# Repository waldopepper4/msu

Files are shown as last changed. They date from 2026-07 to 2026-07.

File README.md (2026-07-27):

[README.md](https://github.com/user-attachments/files/30384597/README.md)
Stoppuhr für die Arduino-IDE bzw. C++. 
Die Stoppuhr kann nur eine voreingestellte Minutenanzahl abwärts zählen. 
Eine Start- /Stopptaste startet bzw. stoppt den Zähler. Der Endwert bleibt so lange im Display stehen, bis die Resettaste gedrückt wird. 
Eine Resettaste setzt den Zähler wieder auf den Anfangswert. 
Ein langes Drücken der Resettaste erlaubt die Minuten einzustellen: mit der Start- / Stopptaste kann der Wert erhöht werden, ein langes Drücken verringert den Minutenwert. Ein nochmaliges Drücken der Resettaste speichert den Minuten-Startwert. 
Bei Überlauf wird eine Minus- bzw. Überzeit solange angezeigt, bis mit der Start- / Stopptaste der Zähler gestoppt wird. Beim Erreichen der letzten 30, 20 und 10 Sekunden ertönt ein Piepser, bei 9,8,7,6,5,4,3,2 und 1 Sekunde weitere kurze Piepstöne und bei 00:00 ein langer Piepston. 
Verwendet wurde microchip ATtiny 3216 mit Display DOGM081.
Wenn die Spannung von 3,1V der Lithium-Batteriezelle unterschritten wird, erscheint "BATTLOW". Der Strombedarf im Betrieb ist ca. 1,7mA, im sleep-Mode 15uA, daher ist kein Ein-/Ausschalter nötig. Die verwendete Batterie hat eine  Sicherheitsschaltung und zusätzlich hat die Ladeschaltung TP4056 eine Batterie-Überwachung.

totale

Angaben zum Gehäuse:
msu.f3d ist der CAD-file für fusion360.
msu.step für andere CAD-Programme verwendbar.
Die *.stl zum direkten Drucken, alle Teile in Drucklage gespeichert.
Gehäuseteile gedruckt mit PCblend, ASA oder ABS im Prusa coreone. 0,2mm Schichthöhe, falls mit Rand, dann Finish der Kanten mit Schleifschwamm nötig.
Start-/Stopp- und Reset-Knopf mit Prusa-MK3S PLA 0,2mm, das transparente Fensterchen mit PETG, 0,1mm Schichthöhe.
Teilelisteund Bezug siehe Tabellenblatt BOM-msu.

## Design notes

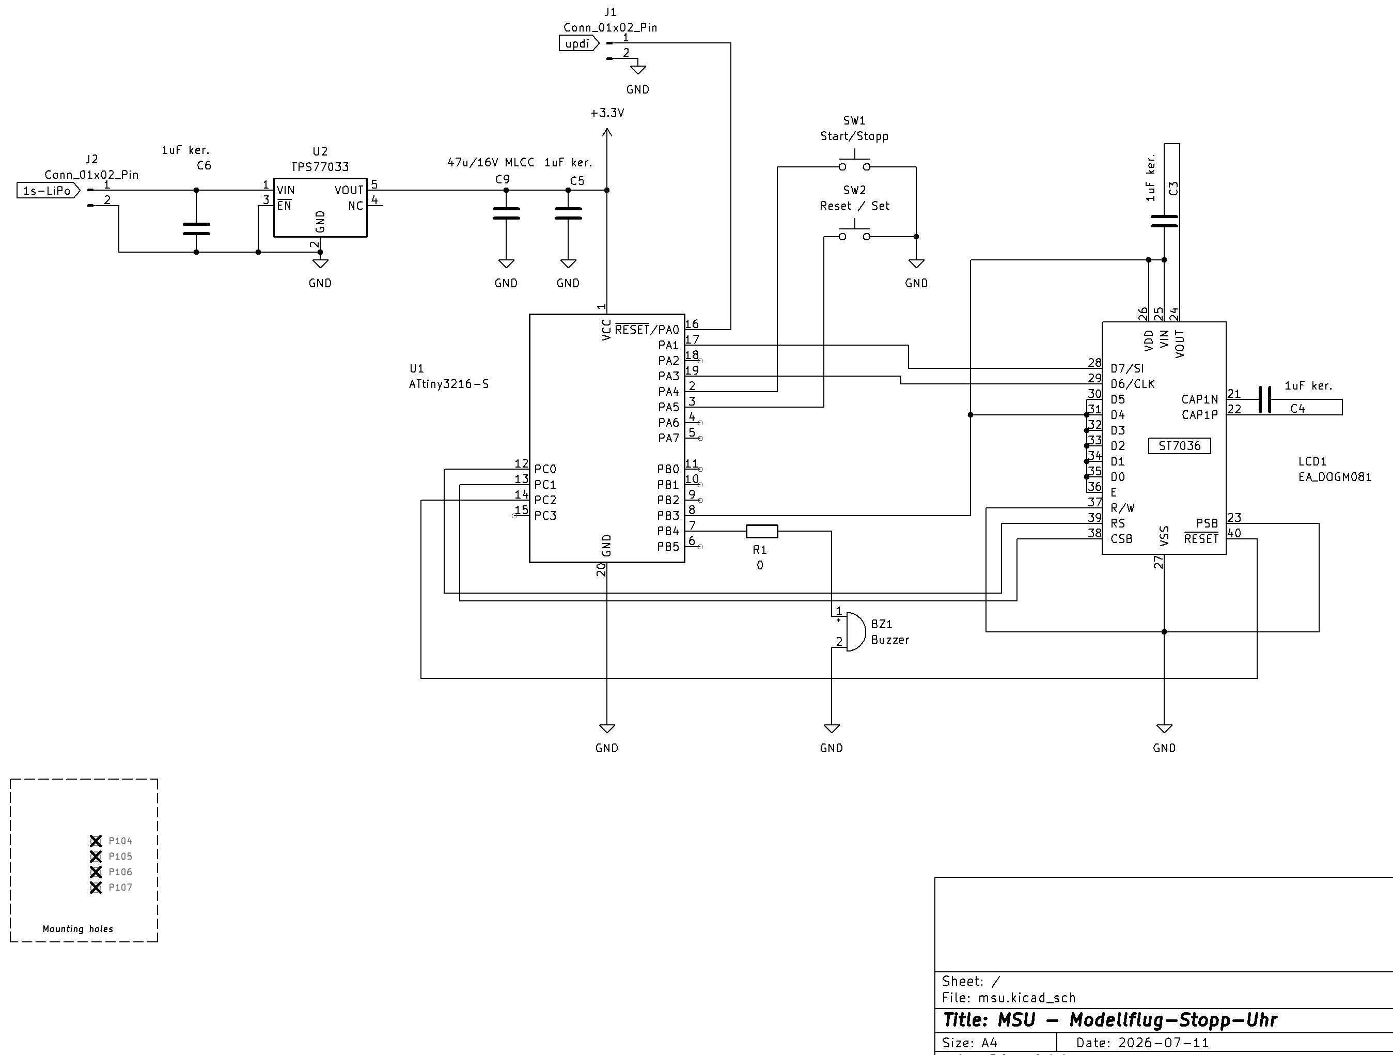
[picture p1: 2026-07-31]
hardware/msu 2026-07-11.jpg

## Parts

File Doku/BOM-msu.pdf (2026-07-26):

Tabelle1

Seite 1

Stk
Stk | Piezosummer, 75 dB, 3,0 V, 4000 Hz, SMD | SMD-P12A03 | reichelt.de | 1,41
Stk | LDO-Festspannungsregler, 2,7 - 10Vin, 3.3Vout, 50mAout, SOT-23-5 | TPS 77033 DBVT | reichelt.de | 1,41
Stk | 8-Bit-ATtiny AVR-RISC Mikrocontroller, 32 kB, 20 MHz, SOIC-20 | ATTINY3216-SN | reichelt.de | 1,76
Stk | SMD-Kerko, 1812, 10 µF, 25 V, 10%, MLCC | ECC KTS250B106K | reichelt.de | 0,57
Stk | 1uF MLCC
Stk | 47uF MLCC
Stk | 0R 0805
1 | IC-Fassung 40pol, lowcost
2 | APEM PHAP3305A PHAP3305A Drucktaster 12 V/DC 0.05 A 1 x Aus/(Ein) tastend | 700019 - 62 | conrad.at | 0,69
1 | Akyga LP523450 Akkupack x Spezial-Akku LiPo 3.7 V 900 mAh | 3385843 - 62 | conrad.at | 9,99
1 | TP4056 1A Lithium-Ionen LiPo Lademodul für Arduino USB-C | BAT7160 | techfun.sk | 0,45
1 | LCD-Textmodul, 29,8 x 10,4 mm, weiß | EA DOGS104N-A | reichelt.de | 6,50
1 | Arduino Nano-Klon mit USB-C | ARD958 | techfun.sk | 5,45
1 | Leerplatine nur 5Stk. Minimumbestellung | Y12-6321110A | jlcpcb.com | 6,00
4 | Senkkopfschraube M2x6
2 | Linsenkpfschraube M2x6
| | | Summe | 34,23 Euro

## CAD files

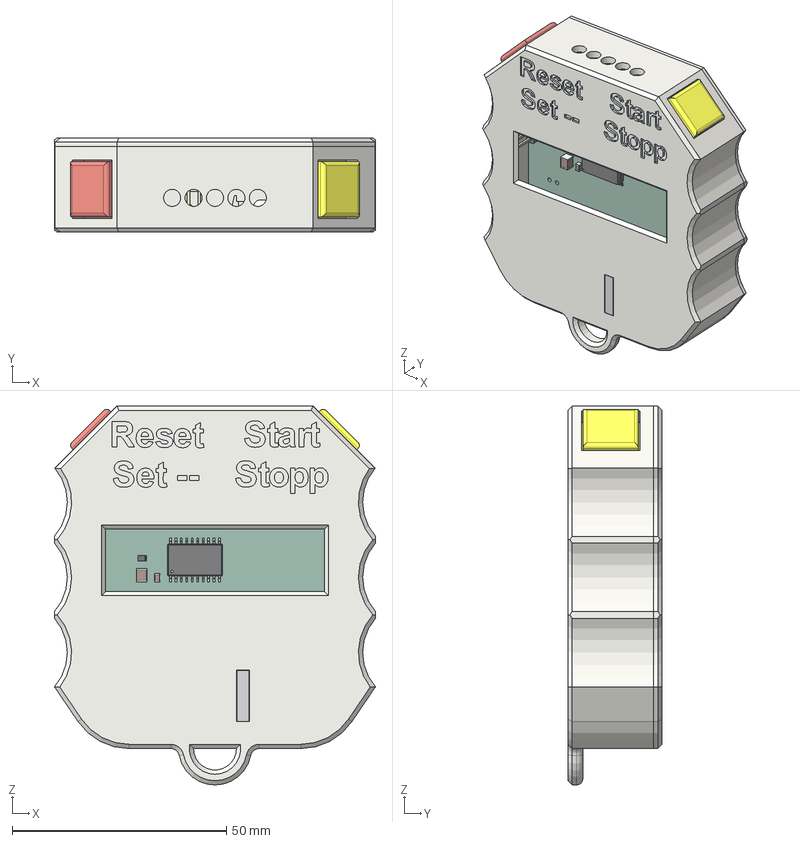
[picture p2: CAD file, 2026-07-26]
STL+CAD/msu.step
74.9 x 22.0 x 88.4 mm
SW_Tactile_SPST_Angled_PTS645Vx31-2LFS x 2
C_0805_2012Metric x 4
SOIC-20W_7.5x12.8mm_P1.27mm
SOT-23-5
PinHeader_1x02_P2.54mm_Vertical x 2
R_0805_2012Metric
C_1210_3225Metric
msu_PCB

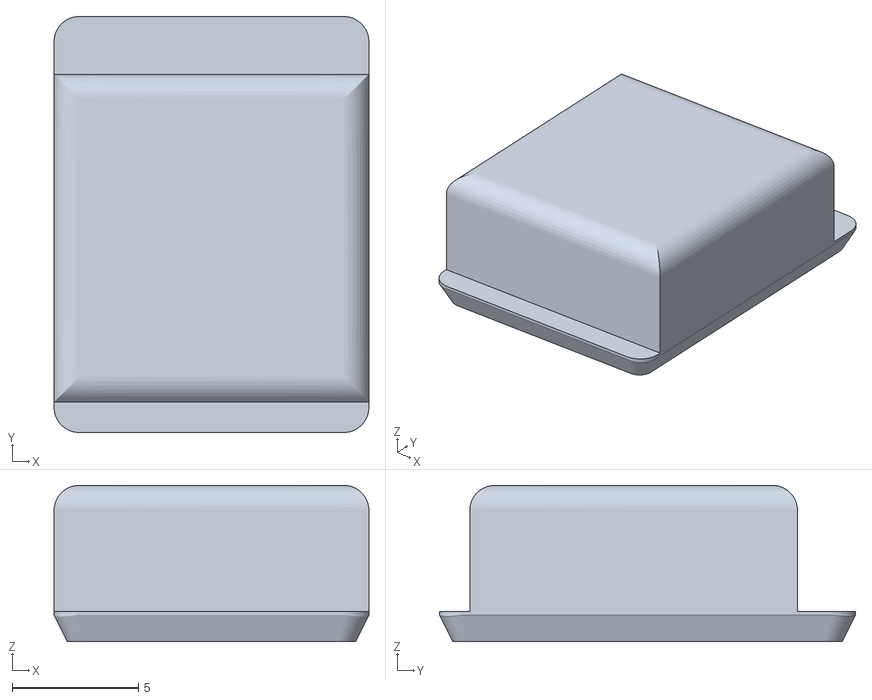
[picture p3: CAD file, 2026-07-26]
STL+CAD/Knopf reset.stl
12.5 x 16.5 x 6.20

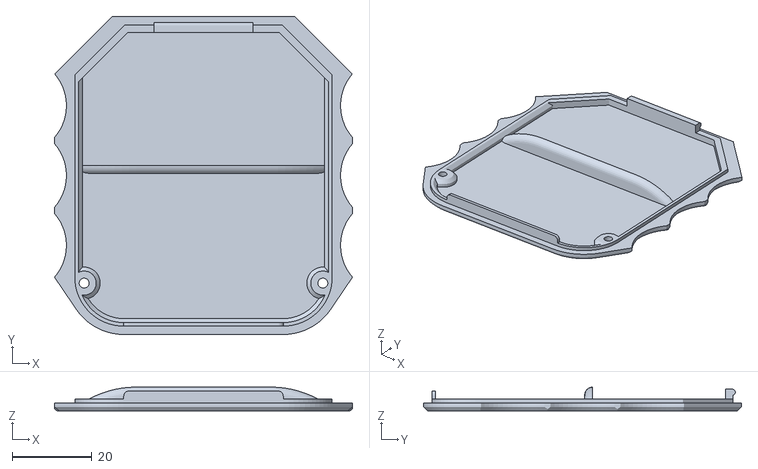
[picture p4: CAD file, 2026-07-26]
STL+CAD/msu-Boden.stl
74.9 x 79.9 x 6.00

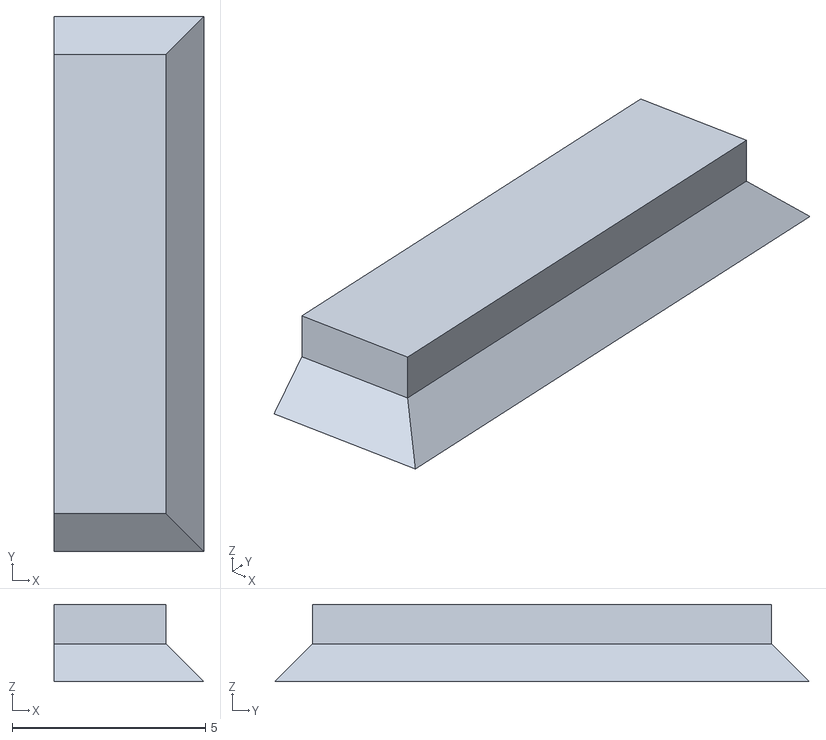
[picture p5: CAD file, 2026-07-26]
STL+CAD/LED-Fenster.stl
3.88 x 13.9 x 2.00

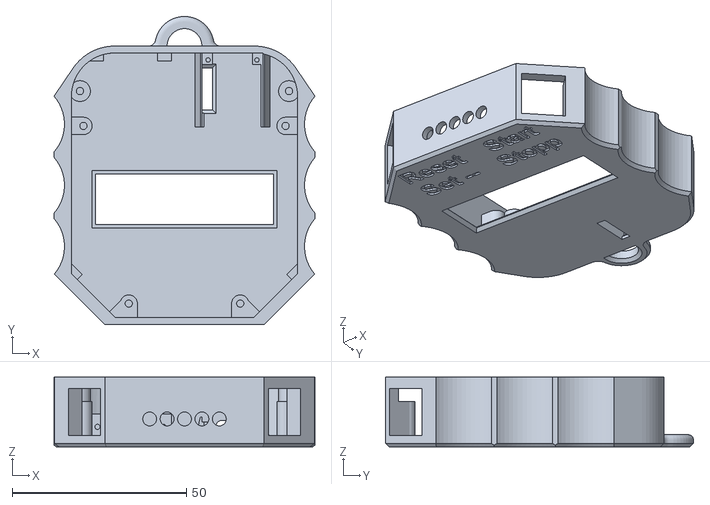
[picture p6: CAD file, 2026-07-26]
STL+CAD/msu-Body.stl
74.9 x 88.4 x 20.0

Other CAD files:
STL+CAD/Knopf StartStopp.stl
STL+CAD/msu.f3d

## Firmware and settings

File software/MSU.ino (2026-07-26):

char Version[] = "23072026";
// Modell Flug Stoppuhr = Abwärtszähler von voreingestellten Minuten mit Überzeitanzeige und Piepser
//  Kein Tastendruck und Zähler zählt nicht + 10 sec. ==> sleep
//                    |------- Arduino pin numbers--------|                       
//                                  +----\/----+                                                    
//                             VDD 1|o         |20 GND      
//     PIN_START_STOP - 0 - PA4 -  2|          |19 - PA3 - 16 - DISPLAY_SCK_PIN                                 
//          PIN_RESET - 1 - PA5 -  3|          |18 - PA2 - 15 -                       
//                    - 2 - PA6 -  4|          |17 - PA1 - 14 - DISPLAY_MOSI_PIN (SI/D7)                 
//                    - 3 - PA7 -  5|          |16 - PA0 - 17 - UPDI                          
//                 NC - 4 - PB5 -  6|          |15 - PC3 - 13 - NC                         
//         PIN_BUZZER - 5 - PB4 -  7|          |14 - PC2 - 12 - DISPLAY_RESET_PIN 
//    DISPLAY_VCC_PIN - 6 - PB3 -  8|          |13 - PC1 - 11 - DISPLAY_CS_PIN (CSB)              
//                    - 7 - PB2 -  9|          |12 - PC0 - 10 - DISPLAY_ DC_PIN (RS) 
//                    - 8 - PB1 - 10|          |11 - PB0  - 9 -  
//                                  +----------+ 
// Software: Arduino IDE 1.8.19 with SpenceKonde/megaTinyCore 2.6.10 installed https://github.com/SpenceKonde/megaTinyCore    
//
// Arduino IDE settings: Chip: "ATtiny3216", Clock: "1 MHz internal", Programmer: "SerialUPDI", other default
//
// Useful links:  
// ATtiny3216 datasheet:     https://ww1.microchip.com/downloads/en/DeviceDoc/ATtiny3216-17-DataSheet-DS40002205A.pdf
//                           https://onlinedocs.microchip.com/oxy/GUID-A2109DC3-B5FF-4E1B-BDB5-622C21D35F43-en-US-5/GUID-0BF2B683-3906-4D3E-BA97-2634FA1779B7.html
// DS3231M datasheet:        https://www.analog.com/media/en/technical-documentation/data-sheets/ds3231m.pdf
// Display EA DOGM081 docs:  https://www.lcd-module.de/lcd-tft-beispiel-code-programmierung/application-note/arduino.html
//                           https://www.lcd-module.de/eng/pdf/doma/dog-me.pdf
// megaTinyCore Power Save           https://github.com/SpenceKonde/megaTinyCore/blob/master/megaavr/extras/PowerSave.md
// megaTinyCore Pin Interrupts       https://github.com/SpenceKonde/megaTinyCore/blob/master/megaavr/extras/Ref_PinInterrupts.md  
// ATtiny UPDI Serial Programmer     https://github.com/SpenceKonde/AVR-Guidance/blob/master/UPDI/jtag2updi.md
// megaTinyCore PWM and Timers       https://github.com/SpenceKonde/megaTinyCore/blob/master/megaavr/extras/Ref_Timers.md
// original: elektormagazine low power timer by anto
//
#include <megaTinyCore.h>       // Core support for ATtiny series SpenceKonde/megaTinyCore 2.6.10 https://github.com/SpenceKonde/megaTinyCore
#include <Arduino.h>
#include <avr/sleep.h>          // AVR Sleep mode definitions
#include <dogm_7036.h>          // Display library and docs EA DOGM081 https://www.lcd-module.com/lcd-tft-code-example-programming/application-note/arduino.html
#include <OneButton.h>
#include <SPI.h>
#include <EEPROM.h>

#define PIN_START_STOP    PIN_PA5
#define PIN_RESET         PIN_PA4
#define PIN_BUZZER        PIN_PB4
#define DISPLAY_VCC_PIN   PIN_PB3                           // Control pin to cut power to display (for power saving)
#define DISPLAY_RESET_PIN PIN_PC2
#define ADC_PIN           PIN_PA2
#define DISPLAY_CS_PIN    PIN_PC1                           // Chip Select for SPI Display
#define DISPLAY_SCK_PIN   PIN_PA3                         // SPI Clock pin

#define unusedPinNum 8                                    // Count of unused pins to set as INPUT_PULLUP for power saving
uint8_t unusedPin[10]  = {2,3,4,7,8,9,13,15}; //2, 3, 4, 7, 8, 9, 13, 15};   // List of unused pins

const int ADC_THRESHOLD = 634;        // Berechneter ADC-Wert für 3,1V Batteriespannung
const uint8_t I2C_ADDR = 0x3C;
byte arrow_down[] = {0x04, 0x04, 0x04, 0x04, 0x15, 0x0E, 0x04, 0x00}; //pattern for own defined character

// Instanzen der Bibliotheken
dogm_7036 DOG;                                      // Display instance   
OneButton btnStartStop;
OneButton btnReset;

// Zustandsautomat für die Stoppuhr
enum State { IDLE, RUNNING, OVERTIME, PAUSED, SETTING, BATTLOW };
State currentState = IDLE;

// Zeitvariablen (in Sekunden)
int32_t initialMinutes = 0; // Voreinstellung: 0 Minuten
int32_t currentSeconds = initialMinutes * 60;
uint32_t lastTickTime = 0;
char bpuffer[10];

// Hilfsvariablen für Nicht-blockierenden Buzzer
uint32_t buzzerEndTime = 0;
bool buzzerActive = false;

// Prototypen
void updateDisplay();
void handleBuzzer(int32_t remainingSec);
void checkBuzzerDuration();
void goSleep();
void Spannungmessen();

// Pin als Eingang definieren
bool emptybatt = false;                 // Statusvariable für niedrigen Batteriestand

uint16_t waketimer = 10;
uint32_t lastTime = 0;

// --- Button-Events ---

// --- Interrupt Service Routine for PORTA (Buttons) ---
ISR(PORTA_PORT_vect){
  
  uint8_t flags = PORTA.INTFLAGS;                            // Read which pins triggered the interrupt
  PORTA.INTFLAGS = flags;                                    // Clear the flags by writing a 1 to them (not a 0);

  if (flags & 0x010){                                         // Check PA4 interrupt fired (start/stopp-button)                                      
      currentState = IDLE;                                     // 1 2 4 8 16 32 64 128
  }                                                       // 1 2 4 8 10 20 40 80 

  if (flags & 0x20){                                         // Check PA5 interrupt fired (reset/set-button)
      currentState = IDLE;                                      
  }  
}

void onStartStopClick() {
  switch (currentState) {
    case BATTLOW:
      updateDisplay();
      delay(2000);
      goSleep();
      break;  
    case SETTING:
      initialMinutes++;
      if (initialMinutes > 99) initialMinutes = 1; // Begrenzung auf 99 Min
      updateDisplay();
      break;
    case IDLE:
      handleBuzzer(9999);
    case PAUSED:
      if (currentSeconds >= 0) {
        currentState = RUNNING;
      } else {
        currentState = OVERTIME;
      }
      lastTickTime = millis();
      updateDisplay();
      break;
    case RUNNING:
    case OVERTIME:
      currentState = PAUSED;
      updateDisplay();
      break;
  }
waketimer=10;
}

void onStartStopLongPress() {
  if (currentState == SETTING) {
    initialMinutes--;
    if (initialMinutes < 1) initialMinutes = 99; // Umlaufschutz
    updateDisplay();
  }
waketimer=10;
}

void onResetClick() {
  switch (currentState) {
    case SETTING:
      // Speichern und Verlassen des Einstellmodus
      currentSeconds = initialMinutes * 60;
      currentState = IDLE;
      updateDisplay();
      break;
    case PAUSED:
    case IDLE:
    case OVERTIME:
      // Zurücksetzen auf Anfangswert
      currentSeconds = initialMinutes * 60;
      currentState = IDLE;
      updateDisplay();
      break;
    default:
      break;
  }
waketimer=10;
}

void onResetLongPress() {
  if (currentState == IDLE || currentState == PAUSED) {
    currentState = SETTING;
    updateDisplay();
  }
  waketimer=10;
}

////////////////////////////////// START SETUP ////////////////////////////////////////////////////////////////////
void setup() {
  // Buzzer-Pin initialisieren
  pinMode(PIN_BUZZER, OUTPUT);
  digitalWrite(PIN_BUZZER, LOW);

  //analogReference(INTERNAL2V5);
  //pinMode(ADC_PIN, INPUT);

// --- Configure Sleep Mode ---
  set_sleep_mode(SLEEP_MODE_PWR_DOWN);                   // Deepest sleep mode
  sleep_enable();
// --- Configure Unused Pins (Prevents floating pins consuming power) ---

  for (uint8_t i = 0; i < unusedPinNum; i++){ 
    pinMode(unusedPin[i], INPUT_PULLUP);   
  }
/*
  pinMode(2, INPUT_PULLUP);
  pinMode(3, INPUT_PULLUP);
  pinMode(4, INPUT_PULLUP);
  pinMode(7, INPUT_PULLUP);
  pinMode(8, INPUT_PULLUP);
  pinMode(9, INPUT_PULLUP);
  pinMode(13, INPUT_PULLUP);
*/
pinMode(PIN_START_STOP, INPUT_PULLUP);
pinMode(PIN_RESET, INPUT_PULLUP);

  EEPROM.get(0x05, initialMinutes);
  currentSeconds = initialMinutes * 60;
  // Display initialisieren
  pinMode(DISPLAY_VCC_PIN, OUTPUT);
  digitalWrite(DISPLAY_VCC_PIN, HIGH);
  delay(100);
  DOG.initialize(11, 0, 0, 10, 12, 0, DOGM081);          // HW Config for Display (CS, 0, 0, DC, RESET, 0, DOGM081)
  DOG.contrast(15); 
  DOG.displ_onoff(true);                                 // Turn Display on
  DOG.cursor_onoff(false);                               // Turn cursor blinking off
  DOG.define_char(0, arrow_down); //define own char on memory adress 0

  // Tasten über OneButton konfigurieren (Aktiv LOW, Pull-Up ein)
  btnStartStop.setup(PIN_START_STOP, INPUT_PULLUP, true);
  btnReset.setup(PIN_RESET, INPUT_PULLUP, true);

  // Event-Handler zuweisen
  btnStartStop.attachClick(onStartStopClick);
  btnStartStop.attachLongPressStart(onStartStopLongPress);
  btnReset.attachClick(onResetClick);
  btnReset.attachLongPressStart(onResetLongPress);
  Spannungmessen(); delay(200); Spannungmessen();
  updateDisplay();
} ////////////////////////////////// ENDE SETUP ////////////////////////////////////////////////////////////////////

void loop() {
  // OneButton Zustände dauerhaft prüfen
  btnStartStop.tick();
  btnReset.tick();

  // Nicht-blockierende Steuerung für den Piepser
  checkBuzzerDuration();

  // Zeit-Logik im Sekundentakt
  if (currentState == RUNNING || currentState == OVERTIME) {
    if (millis() - lastTickTime >= 1000) {
      lastTickTime += 1000;

      if (currentState == RUNNING) {
        currentSeconds--;
        handleBuzzer(currentSeconds); // Töne ausgeben

        if (currentSeconds <= 0) {
          currentState = OVERTIME;
        }
      } else if (currentState == OVERTIME) {
        currentSeconds--; // Zählt im negativen Bereich weiter (-1, -2...)
      }
      updateDisplay();
    }
  waketimer=10;  
  }
if (millis() - lastTime >= 1000) {
  lastTime += 1000;
  waketimer-=1;  
  }
  if(!waketimer) goSleep();
}

// --- Hilfsfunktionen ---

void updateDisplay() {
  DOG.clear_display();
  DOG.position(1,1);
  switch (currentState) {
    case IDLE:     break;
    case RUNNING:  DOG.string("   "); break;
    case OVERTIME: DOG.string(" - "); break;
    case PAUSED:   if (currentSeconds < 0 && currentState != SETTING) DOG.string(" - "); else DOG.string("end"); break;  
    case SETTING:  DOG.string("set"); break;
    case BATTLOW:  DOG.string("low"); break;
  }

  // Zeitausgabe (Format: MM:SS oder -MM:SS)
  DOG.position(4,1);
  int32_t absSeconds = abs(currentSeconds);
  int32_t displayMin = (currentState == SETTING) ? initialMinutes : (absSeconds / 60);
  int32_t displaySec = (currentState == SETTING) ? 0 : (absSeconds % 60);

  sprintf(bpuffer,"%02d:%02d", (int)displayMin, (int)displaySec);
  DOG.string(bpuffer);
}

void startBeep(uint32_t durationMs,unsigned int freq) {
  tone(PIN_BUZZER,freq);
  buzzerEndTime = millis() + durationMs;
  buzzerActive = true;
}

void checkBuzzerDuration() {
  if (buzzerActive && millis() >= buzzerEndTime) {
    noTone(PIN_BUZZER);
    buzzerActive = false;
  }
}

void handleBuzzer(int32_t remainingSec) {
  if (remainingSec == 30 || remainingSec == 20 || remainingSec == 10) {
    startBeep(250,1500); // Normaler Piepston bei 30, 20, 10 Sek.
  } 
  else if (remainingSec >= 1 && remainingSec <= 9) {
    startBeep(100,2000); // Kurze Piepstöne von 9 bis 1 Sek.
  } 
  else if (remainingSec == 0 || remainingSec == 9999) {
    startBeep(1500,900); // Langer Piepston bei Null
  }
  else if (!(remainingSec % 60)) {
    startBeep(500,1000); 
  }
}


// --- Battery Check (using internal VCC reading) ---
void Spannungmessen() {
  int16_t voltageReading = readSupplyVoltage();      // readSupplyVoltage() is usually part of a specific AVR library extension (3.3V = 3300mV)

  if (voltageReading < 3100) {                        // Threshold < 3.1V
    emptybatt = true; currentState=BATTLOW;
  } else { 
    emptybatt = false; currentState=IDLE;
  }
}

void goSleep(){
  DOG.clear_display();                          
  delay(500);
  DOG.displ_onoff(false);                         // Turn display on
  SPI.end();
  digitalWrite(DISPLAY_CS_PIN, LOW);             // Set communication pins LOW *
  digitalWrite(DISPLAY_RESET_PIN, LOW);
  digitalWrite(DISPLAY_SCK_PIN, LOW); 

  digitalWrite(PIN_BUZZER, LOW);
  digitalWrite(DISPLAY_VCC_PIN, LOW);            // Cut power to display module
  
  EEPROM.put(0x05,initialMinutes);               // Aktuell konfigurierte Startzeit retten
  PORTA.PIN4CTRL |= PORT_ISC_LEVEL_gc;         // Enable Asynchronous Interrupts for Wake-up
  PORTA.PIN5CTRL |= PORT_ISC_LEVEL_gc;         // PA4 (Start/Stopp-button) and PA5 (Re/Set-Btn) -> Trigger on Falling Edge

  sleep_cpu();                                   // Enter sleep (CPU halts here)

  // ======= WAKE UP POINT =======
  
  PORTA.PIN4CTRL &= ~PORT_ISC_gm;                // Disable Interrupts immediately after wake up
  PORTA.PIN5CTRL &= ~PORT_ISC_gm;

  digitalWrite(DISPLAY_VCC_PIN, HIGH);           // Restore display power
  delay(100);
  
  DOG.initialize(11, 0, 0, 10, 12, 0, DOGM081);  // Re-init display and SPI
  DOG.contrast(15); 
  DOG.displ_onoff(true);                         // Turn display on
  DOG.cursor_onoff(false);
  waketimer = 10;                   // Reset idle timer

  Spannungmessen();                         // Battery check
  updateDisplay();
}

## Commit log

2026-07-26 Create STL + CAD
2026-10-25 Add files via upload
    -> use better suitable buzzer with integrated generator for sound soldered on SMD-pads (bend pins 90°). Therefore firmware does only switch on / off.
    EKULIT RMP-14SP (reichelt.de)
